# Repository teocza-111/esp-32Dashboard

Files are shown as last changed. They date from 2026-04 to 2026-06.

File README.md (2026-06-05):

# Overview
An esp-32 based dashboard with a 4.2" e-ink display from waveshare.
## Why?
Its main purpouse is just sitting on a desk and looking nice, nothing much besides that.
## Features
- Displaying current spotify playing song
- Time and date
- Weather
- [WIP]
# Part List
- [Seeed Studio Xiao ESP32-S3 Plus](https://kamami.pl/xiao/1195704-xiao-esp32s3-plus-plytka-rozwojowa-z-mikrokontrolerem-esp32s3-5906623496303.html)
- [Waveshare 4.2" e-ink display](https://botland.com.pl/wyswietlacze-e-paper/9655-e-paper-e-ink-42-400x300px-modul-z-wyswietlaczem-spi-waveshare-13353-5904422338312.html)
- [4000mAh li-po](https://botland.com.pl/akumulatory-li-pol-1s-37v/15644-akumulator-li-pol-akyga-4000mah-1s-37v-zlacze-jst-bec-gniazdo-80x50x8mm-5904422343644.html)
- 2 * 100kOhm Resistors -- i already own them
- [JST-BEC female adapter](https://botland.com.pl/akcesoria-do-akumulatorow/2865-para-konektorow-jst-bec-do-akumulatorow-li-pol-5904422331221.html)
- Male pin headers 8x2.54mm -- They come with the display
# Media
## Schematics & PCB
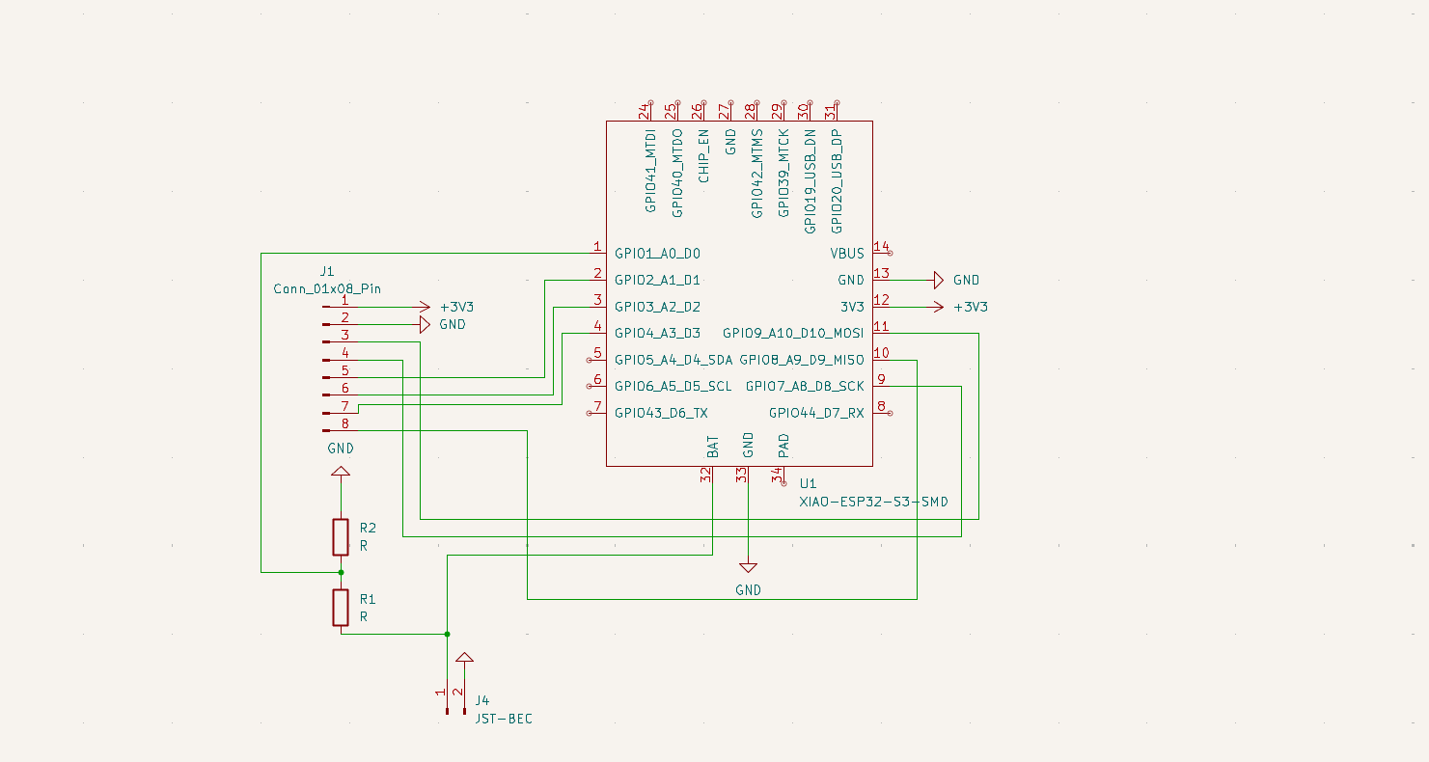
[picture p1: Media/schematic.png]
sch

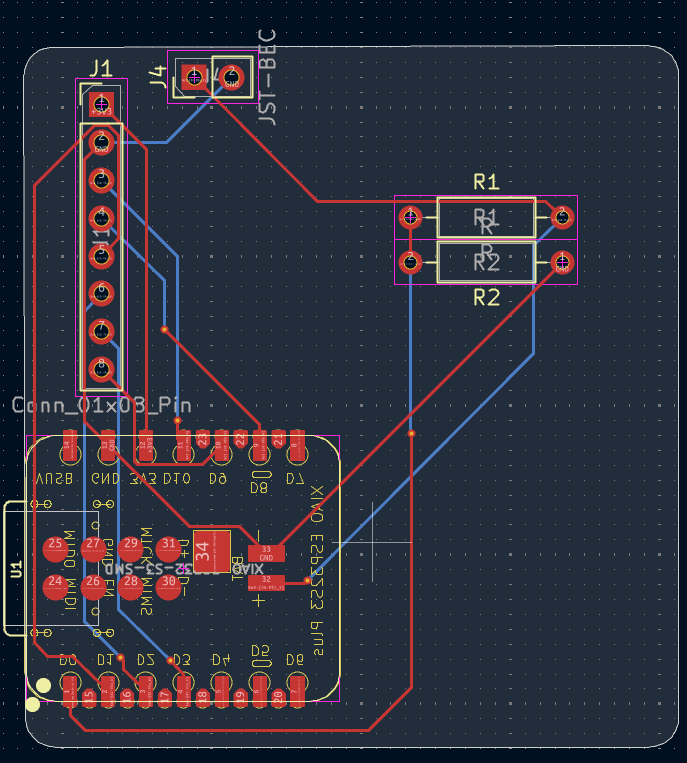
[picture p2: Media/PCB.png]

## Renders [WIP]
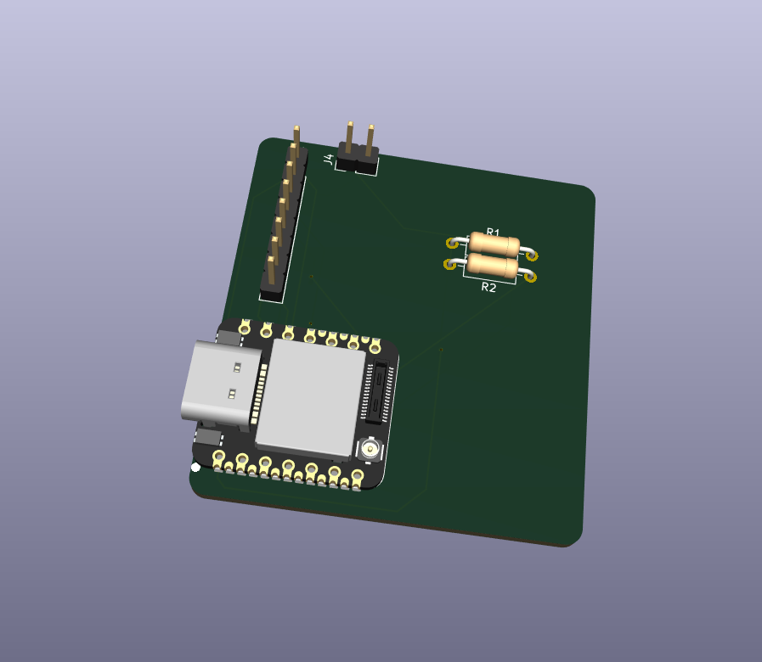
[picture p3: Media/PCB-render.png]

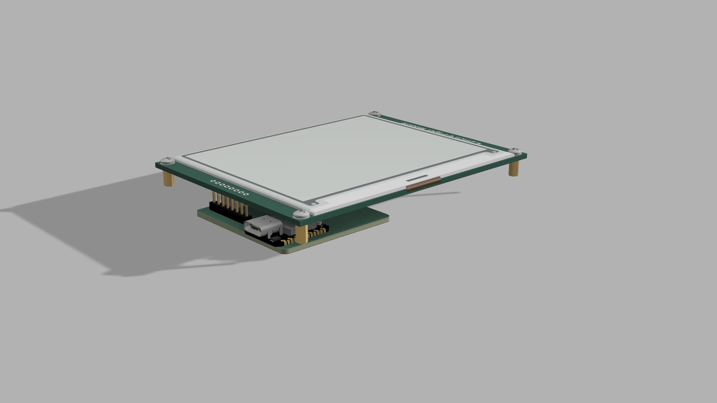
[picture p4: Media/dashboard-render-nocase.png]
V0

## Bill of materials
|Name |Purpose |Quantity|Total Cost (USD)|Link |Distributor |
|---|---|---|---|---|---|
|JST-PH 2.0 Female |Connecting the battery to the mcu |1 |0.84 |https://pl.aliexpress.com/item/4000199807342.htm |AliExpress |
|100kOhm Resistors |Safely reading the volatage of the battery|2 |0.00 | |My resistor kit|
|4000mAh li-po battery |The power source |1 |9.48 |https://pl.aliexpress.com/item/1005009889665207.html|AliExpress |
|Seeed Studio Xiao ESP32-S3 Plus|MCU |1 |12.46 |https://pl.aliexpress.com/item/1005010291070801.html|AliExpress |
|Waveshare 4.2" e-ink display |The display |1 |39.44 |https://pl.aliexpress.com/item/1005004260969887.html|AliExpress |
|PCB |It's... Well a PCB |1 |10.00 | |JLCPCB |

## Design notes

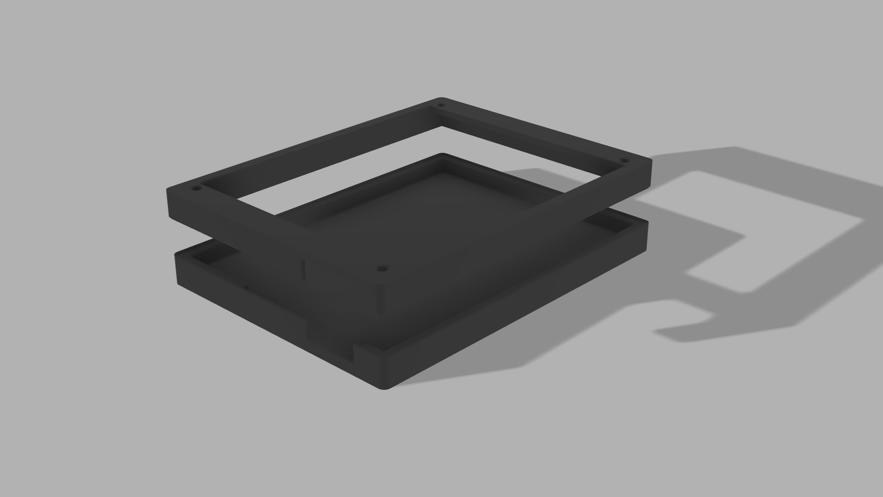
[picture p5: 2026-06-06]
Media/V1render.png

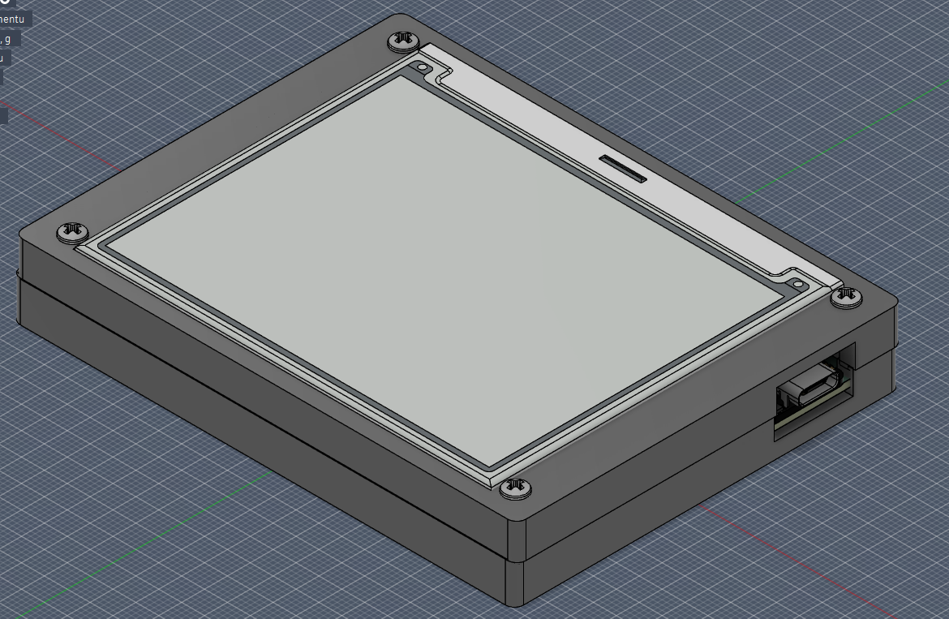
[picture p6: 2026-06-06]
Media/v1.png

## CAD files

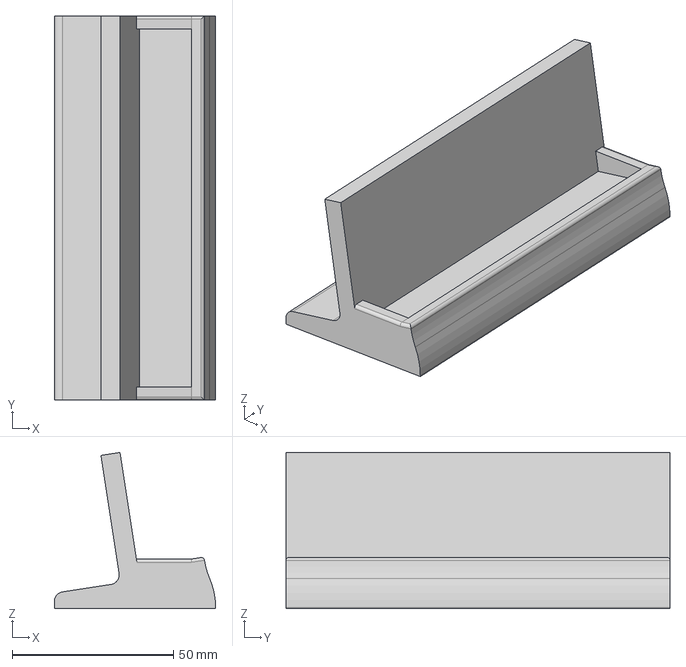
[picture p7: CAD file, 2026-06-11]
STL + STEP/Stand.step
50.0 x 119.0 x 48.4 mm

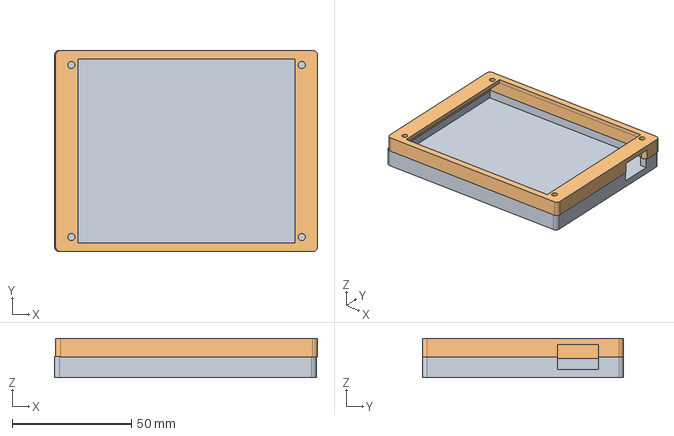
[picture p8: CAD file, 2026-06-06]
STL + STEP/v1.step
110.5 x 84.5 x 16.5 mm

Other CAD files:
STL + STEP/Stand.f3d
STL + STEP/Stand.stl
STL + STEP/v1.f3d
STL + STEP/v1.stl

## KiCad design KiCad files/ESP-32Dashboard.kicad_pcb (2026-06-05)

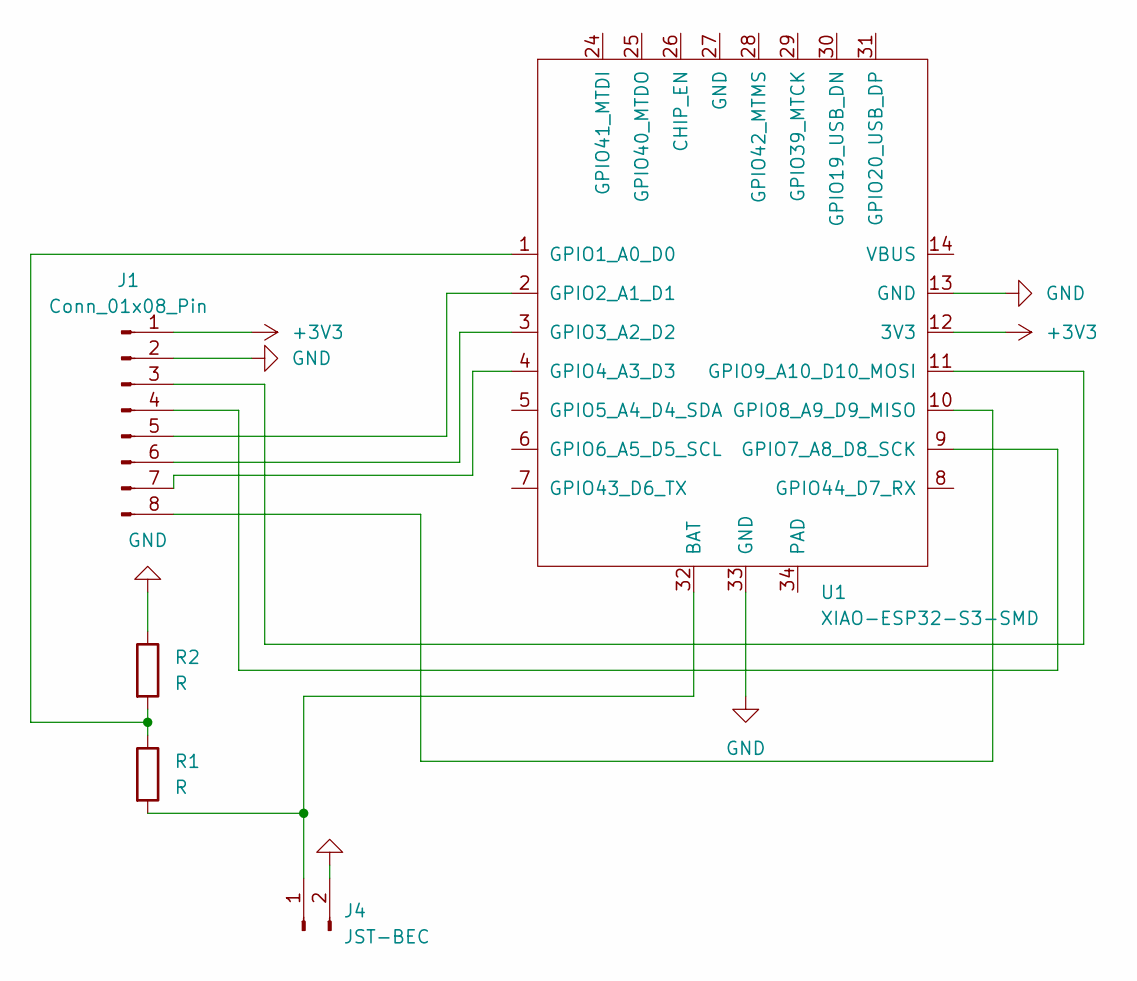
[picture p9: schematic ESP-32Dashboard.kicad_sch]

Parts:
J1: Conn_01x08_Pin; PinHeader_1x08_P2.54mm_Vertical
J4: JST-BEC; PinHeader_1x02_P2.54mm_Vertical
R1, R2: R; R_Axial_DIN0207_L6.3mm_D2.5mm_P10.16mm_Horizontal
U1: XIAO-ESP32-S3-SMD; XIAO-ESP32-S3-Plus-SMD

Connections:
+3V3: J1.1, U1.12 (3V3)
GND: J1.2, J4.2, R2.1, U1.13 (GND), U1.33 (GND)
unnamed: J1.3, U1.11 (GPIO9_A10_D10_MOSI)
unnamed: J1.4, U1.9 (GPIO7_A8_D8_SCK)
unnamed: J1.5, U1.2 (GPIO2_A1_D1)
unnamed: J1.6, U1.3 (GPIO3_A2_D2)
unnamed: J1.7, U1.4 (GPIO4_A3_D3)
unnamed: J1.8, U1.10 (GPIO8_A9_D9_MISO)
unnamed: J4.1, R1.2, U1.32 (BAT)
unnamed: R1.1, R2.2, U1.1 (GPIO1_A0_D0)

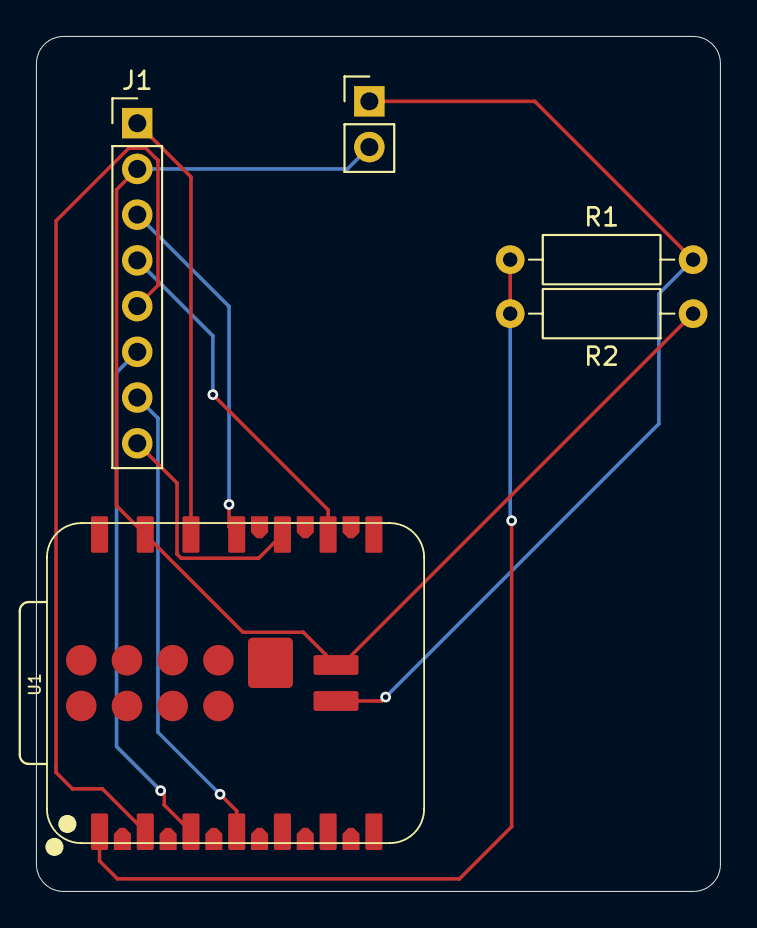
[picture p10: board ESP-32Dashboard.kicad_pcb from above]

Board: 2 copper layers, 38.0 x 47.5 mm, 5 parts (0 on the bottom side), 10 nets.

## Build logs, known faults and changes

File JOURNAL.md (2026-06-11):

---
title: "esp32-Dashboard"
author: "teocza"
description: "Esp32-based desk dashboard with an e-ink display"
created_at: "2026-05-30"
---

# 4/25/2026 1 PM - Research and PCB
_Time spent: 5h_

So I wanted to make something that would look nice on my desk and it landed on a dashboard.
I got inspired by the spotify displays that people make so I want this to also be integrated with my spotify.

More on what will this exactly do will come when i start making the firmware.

anyway

Today I made the overall part list schematic and PCB

The main mcu is a seeed studio esp32-s3 plus, the display will be connected using SPI (the 8 male pin header). The battery has a JST-PH 2.0 male connector so i decided to include a female one(resembled by the 2 male pin header) on the pcb for easy connection.
2 * 100k ohms resistors to read the battery voltage (ADC)

PCB-render
The board may seem a bit big but the display will be even bigger so it doesnt really matter.

I couldn't decide between a few diffrent board but it landed on the Seeed studio esp32-s3 plus, it has abattery voltage regulator,charging and voltage reading capebilities

I'll also make a short README.md on the github repo after writing this journal



# 5/5/2026 7 PM - Quick PCB update and new renders

_Time spent: 0.25h_

Made the JST-PH female port on the pcb more accesible so the battery cable doesn't bend that much,

Also gave my README.md a quick update with all the new screenshots and renders,
I'll start working on the case and firmware soon since the pcb is finished (or so I hope)

dashboard-render-nocase



# 5/9/2026 6 PM - Firmware and other minor thing

_Time spent: 4.5h_

Added all the parts to the bill of material,

Started working on my firmware, looked into the spotify display guide for some help authenticating my spotify account, added time fetching and weather data fetching using open meteo.
```
const char* WEATHER_URL =
  "https://api.open-meteo.com/v1/forecast"
  "?latitude=0000&longitude=0000"
  "&current=temperature_2m";
```
 Connecting to my home wifi etc.
I didn't yet add drawing the info to the screen, just fetching.
I decided to paste this into claude to find any mistakes and see if i can improve something but it just said that "yeah your thing is bs look at this" and basically re-did the whole thing
well i cant really complain since i dont really enjoy coding and i have my finals on monday so after that ill have soooo much time for debugging all of that

here are some screenshots

Zrzut ekranu (105)

Zrzut ekranu (104)

ill still count the time it took me to research all the libraries write the original code make the bom etc.

i also (will after writing this) expanded the earlier entries in the journal with some more info




# 5/24/2026 6 PM - Finished the firmware

_Time spent: 1.5h_

Assigned pins, made the code actually work with hardware
I used claude for a clean display layout (forgive me)
The rest i did by hand
Zrzut ekranu (120)
will start designing the case asap



# 5/30/2026 8 PM - Started the CAD

_Time spent: 2h_

I don't have any photos yet since i forgot to take any and im wirting this on a laptop,
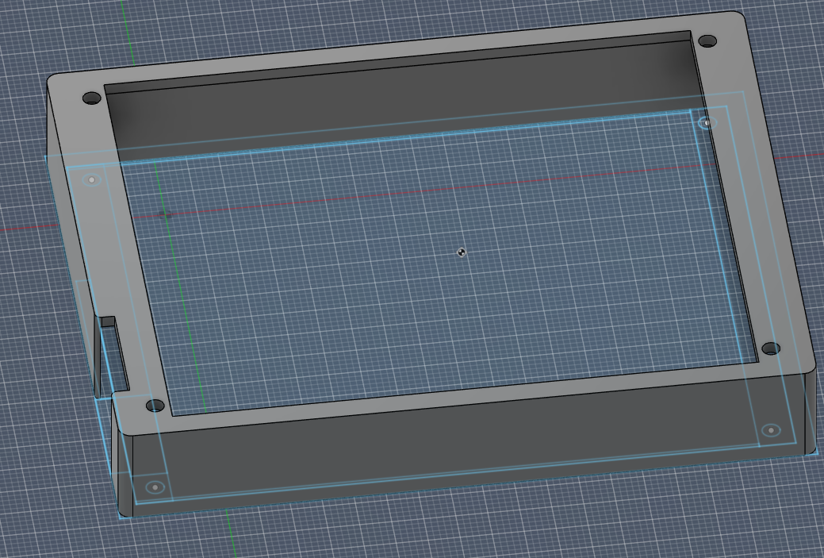
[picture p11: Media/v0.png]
v0

I made the first part of the case, the idea is that there will be a plate that i will be able to slide into the main housing
Also a stand-thingy would be nice, will think abt that

# 6/6/2026 9 PM - V0 and V1 case

_Time spent: 4h_

Finished the V0 case design
v0
but then when i tried fitting a model of the display i realised i messed up some dimensions
I got to work on the v1, double checked every dimension etc.
The idea for this one is a simple two part casing that i will glue together later
Basically done apart from the stand, i dont really have an idea for them yet
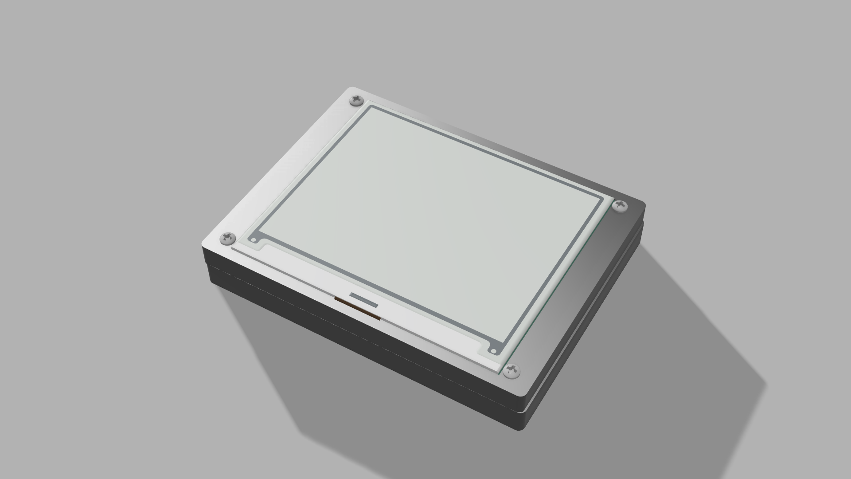
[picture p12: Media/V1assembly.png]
v1assembly

(js ignore that it isnt aligned properly)
+ a quick pcb update since the edges werent asactly straight etc, should be a tiny but smaller now too

# 6/11/2026 7PM - Created a stand for the case

_Time spent: 0.5h_

Made a simple stand meant to hold the case, really nothing to talk about here
This didn't take much time doesn't look spectacular.
I really have no clue what to talk about in here sooo, yeah that should be the end of the design phase i hope this gets accepted
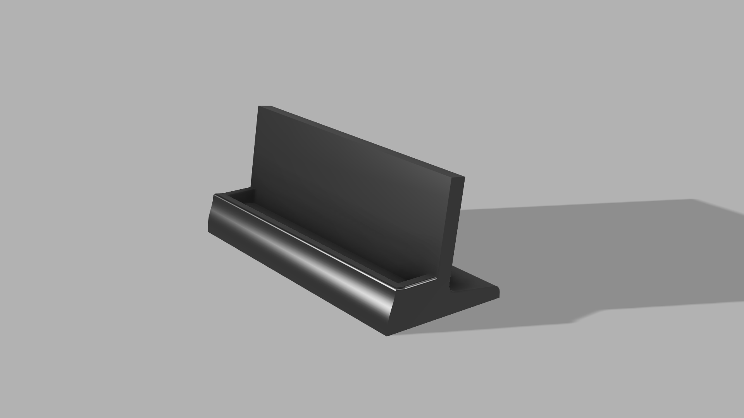
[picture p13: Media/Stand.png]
stand


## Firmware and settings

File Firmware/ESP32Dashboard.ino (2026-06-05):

#define DISABLE_LIBRARY
#define DISABLE_PLAYLISTS
#define DISABLE_METADATA
#define DISABLE_USER
#define DISABLE_SIMPLIFIED

#include <SpotifyEsp32.h>
#include <WiFi.h>
#include <time.h>
#include <HTTPClient.h>
#include <ArduinoJson.h>
#include <SPI.h>
#include <GxEPD2_BW.h>
#include <Fonts/FreeSans9pt7b.h>
#include <Fonts/FreeSans12pt7b.h>
#include <Fonts/FreeSansBold12pt7b.h>
#include <Fonts/FreeSansBold18pt7b.h>
#include "secrets.h"

#define EPD_MOSI  9
#define EPD_SCK   7
#define EPD_CS    2
#define EPD_DC    3
#define EPD_RST   4
#define EPD_BUSY  8
#define BAT_ADC   1

GxEPD2_BW<GxEPD2_420, GxEPD2_420::HEIGHT> display(
  GxEPD2_420(EPD_CS, EPD_DC, EPD_RST, EPD_BUSY)
);

const char* WEATHER_URL =
  "https://api.open-meteo.com/v1/forecast"
  "?latitude=53.01&longitude=18.60"
  "&current=temperature_2m";


const unsigned long SPOTIFY_REFRESH_MS = 40000;
const unsigned long WEATHER_REFRESH_MS = 600000;

Spotify sp(SPOTIFY_CLIENT_ID, SPOTIFY_CLIENT_SECRET);

unsigned long lastSpotifyRefresh = 0;
unsigned long lastWeatherRefresh = 0;

struct DashboardData {
  String track     = "—";
  String artist    = "—";
  bool   isPlaying = false;
  float  tempC     = NAN;
  int    hour      = -1;
  int    lastDrawnHour = -2;
  float  batteryV  = 0.0f;
} data;

void fetchSpotify();
void fetchWeather();
void fetchTime();
void fetchBattery();
void drawDashboard();
void drawCentered(const char* text, int y);

void setup() {
  Serial.begin(115200);
  delay(500);
  Serial.println("[boot] Starting...");

  WiFi.begin(WIFI_SSID, WIFI_PASSWORD);
  Serial.print("[wifi] connecting");
  while (WiFi.status() != WL_CONNECTED) {
    delay(1000);
    Serial.print(".");
  }
  Serial.printf("\n[wifi] Connected. IP: %s\n", WiFi.localIP().toString().c_str());

  configTime(7200, 0, "pool.ntp.org");
  Serial.print("[ntp] syncing");
  struct tm t;
  while (!getLocalTime(&t)) {
    delay(500);
    Serial.print(".");
  }
  Serial.println("\n[ntp] Synced.");

  SPI.begin(EPD_SCK, -1, EPD_MOSI, EPD_CS);
  display.init(115200, true, 2, false);
  display.setRotation(1);
  display.setTextColor(GxEPD_BLACK);

  display.setFullWindow();
  display.firstPage();
  do {
    display.fillScreen(GxEPD_WHITE);
    display.setFont(&FreeSansBold18pt7b);
    drawCentered("Dashboard", 120);
    display.setFont(&FreeSans9pt7b);
    drawCentered("connect to sptify:", 165);
    String url = "http://" + WiFi.localIP().toString() + "/login";
    drawCentered(url.c_str(), 190);
  } while (display.nextPage());

  sp.begin();
  Serial.printf("[spotify] Auth URL: http://%s/login\n", WiFi.localIP().toString().c_str());
  while (!sp.is_auth()) {
    sp.handle_client();
  }
  Serial.println("[spotify] authenticated.");

  fetchTime();
  fetchWeather();
  fetchSpotify();
  fetchBattery();
  drawDashboard();

  lastSpotifyRefresh = millis();
  lastWeatherRefresh = millis();
}

void loop() {
  sp.handle_client();

  unsigned long now = millis();

  bool redraw = false;

  if (now - lastSpotifyRefresh >= SPOTIFY_REFRESH_MS) {
    lastSpotifyRefresh = now;
    fetchTime();
    fetchBattery();
    fetchSpotify();
    redraw = true;
  }

  if (now - lastWeatherRefresh >= WEATHER_REFRESH_MS) {
    lastWeatherRefresh = now;
    fetchWeather();
    redraw = true;
  }

  if (redraw) {
    drawDashboard();
  }
}


void fetchSpotify() {
  player_currently_playing_t result;
  if (!sp.currently_playing(result)) {
    Serial.println("[spotify] Nothing playing or fetch failed.");
    data.track     = "Nothing playing rn";
    data.artist    = "";
    data.isPlaying = false;
    return;
  }
  data.isPlaying = result.is_playing;
  data.track     = String(result.item.name);
  data.artist    = String(result.item.artists[0].name);
  Serial.printf("[spotify] %s – %s\n", data.artist.c_str(), data.track.c_str());
}

void fetchWeather() {
  HTTPClient http;
  http.begin(WEATHER_URL);
  int code = http.GET();
  if (code != 200) {
    Serial.printf("[weather] HTTP error %d\n", code);
    http.end();
    return;
  }
  JsonDocument doc;
  DeserializationError err = deserializeJson(doc, http.getStream());
  http.end();
  data.tempC = doc["current"]["temperature_2m"].as<float>();
  Serial.printf("[weather] %.1f°C\n", data.tempC);
}

void fetchTime() {
  struct tm t;
  if (!getLocalTime(&t)) {
    Serial.println("[time] Failed.");
    return;
  }
  data.hour = t.tm_hour;
}

void fetchBattery() {
  int raw = analogRead(BAT_ADC);
  data.batteryV = raw * (3.3f / 4095.0f) * 2.0f;
}

void drawDashboard() {
  Serial.println("[epd] Drawing...");

  int16_t x1, y1;
  uint16_t tw, th;

  display.setFullWindow();
  display.firstPage();
  do {
    display.fillScreen(GxEPD_WHITE);

    display.fillRect(0, 0, 400, 50, GxEPD_BLACK);
    display.setTextColor(GxEPD_WHITE);

    char hourStr[8];
    snprintf(hourStr, sizeof(hourStr), "%02d:00", data.hour >= 0 ? data.hour : 0);
    display.setFont(&FreeSansBold18pt7b);
    display.setCursor(12, 38);
    display.print(hourStr);

    char tempStr[12];
    if (isnan(data.tempC)) {
      snprintf(tempStr, sizeof(tempStr), "--°C");
    } else {
      snprintf(tempStr, sizeof(tempStr), "%.1f°C", data.tempC);
    }
    display.setFont(&FreeSansBold18pt7b);
    display.getTextBounds(tempStr, 0, 0, &x1, &y1, &tw, &th);
    display.setCursor(400 - tw - 12 - x1, 38);
    display.print(tempStr);

    display.setTextColor(GxEPD_BLACK);

    String playIcon = data.isPlaying ? "> " : "|| ";
    String track = data.track.length() > 22
                 ? data.track.substring(0, 21) + "~"
                 : data.track;
    String trackLine = playIcon + track;

    display.setFont(&FreeSansBold12pt7b);
    display.getTextBounds(trackLine.c_str(), 0, 0, &x1, &y1, &tw, &th);
    display.setCursor((400 - tw) / 2 - x1, 135);
    display.print(trackLine);

    display.setFont(&FreeSans12pt7b);
    String artist = data.artist.length() > 30
                  ? data.artist.substring(0, 29) + "~"
                  : data.artist;
    display.getTextBounds(artist.c_str(), 0, 0, &x1, &y1, &tw, &th);
    display.setCursor((400 - tw) / 2 - x1, 165);
    display.print(artist);

    display.drawLine(0, 200, 400, 200, GxEPD_BLACK);

    float pct = constrain((data.batteryV - 3.0f) / 1.2f, 0.0f, 1.0f);
    int barFill = (int)(120 * pct);
    display.drawRect(10, 212, 122, 20, GxEPD_BLACK);
    display.fillRect(132, 217, 4, 10, GxEPD_BLACK);
    display.fillRect(11, 213, barFill, 18, GxEPD_BLACK);

    display.setFont(&FreeSans9pt7b);
    char batStr[12];
    snprintf(batStr, sizeof(batStr), "%.2fV", data.batteryV);
    display.setCursor(142, 228);
    display.print(batStr);

    display.setCursor(300, 228);
    display.print("WiFi: ");
    display.print(WiFi.status() == WL_CONNECTED ? "OK" : "--");

  } while (display.nextPage());

  Serial.println("[epd] Done.");
}

void drawCentered(const char* text, int y) {
  int16_t x1, y1;
  uint16_t w, h;
  display.getTextBounds(text, 0, 0, &x1, &y1, &w, &h);
  display.setCursor((400 - w) / 2 - x1, y);
  display.print(text);
}

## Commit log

2026-04-25 Added Kicad and media files
    [ESP-32Dashboard.kicad_pcb]
2026-05-05 Small changes to the pcb + new renders
    [ESP-32Dashboard.kicad_pcb, ESP-32Dashboard.kicad_sch]
2026-05-05 Enhance README with part details and media section
    Updated part list with a link for the 4000mAh li-po battery and added media section with schematics, PCB, and renders.
2026-05-30 Added a BoM
    [esp-32Dashboard-bom.csv]
2026-05-30 Add bill of materials to README
    Added a bill of materials section with details on components used in the project.
2026-05-30 Update JOURNAL.md with project details
    Added metadata for the esp32-Dashboard project.
2026-05-30 Revise time entries and add CAD progress
    Updated time spent on various tasks and added new entry for CAD work.
2026-05-31 Revise JOURNAL.md with recent project updates
    Updated journal entries with new research, PCB details, and firmware progress. Added images and clarified time spent on tasks.
2026-06-05 fixed edge.cuts
    [ESP-32Dashboard.kicad_pcb]
2026-06-06 V1 case
    [v1.f3d, v1.step, v1.stl]
2026-06-11 Created the stand
    [Stand.f3d, Stand.step, Stand.stl]
